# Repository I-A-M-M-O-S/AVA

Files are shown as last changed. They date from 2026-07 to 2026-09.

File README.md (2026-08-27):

# Ava
*Autonomous Vehicle for Alex*
## Goal
Autonomous 1:10 RC-Car utilizing a Jetson Orin System.

## Hardware

### Custom PCB
All the different ECUs and sensors need to be connected.
Point-to-point wiring is one option but very messy and prone to EMI, using a custom PCB instead.

PCB-Schematic
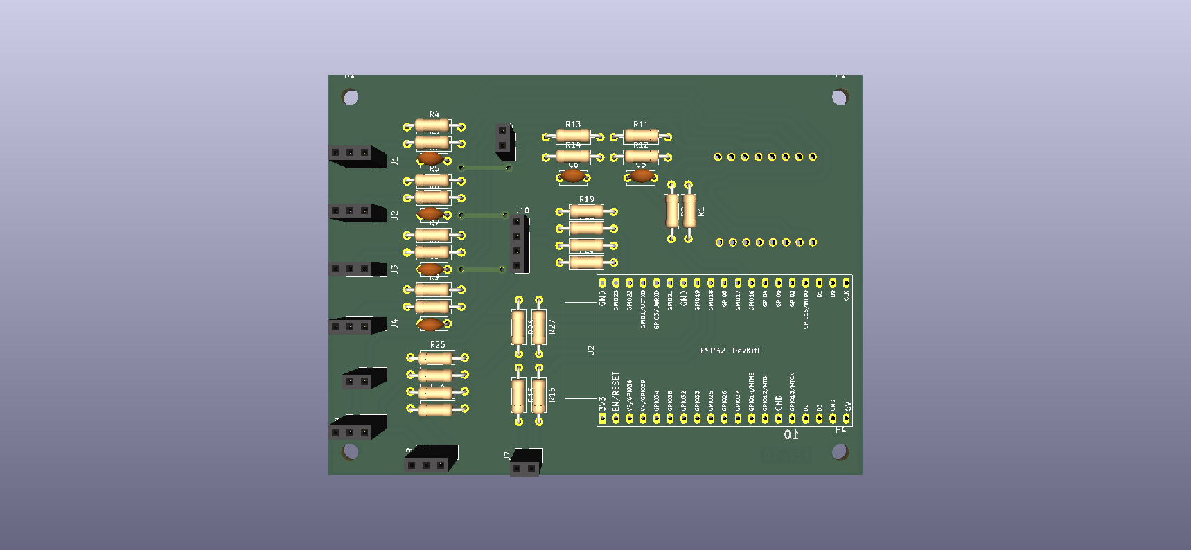
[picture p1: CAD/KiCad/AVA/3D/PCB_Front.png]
PCB-Front

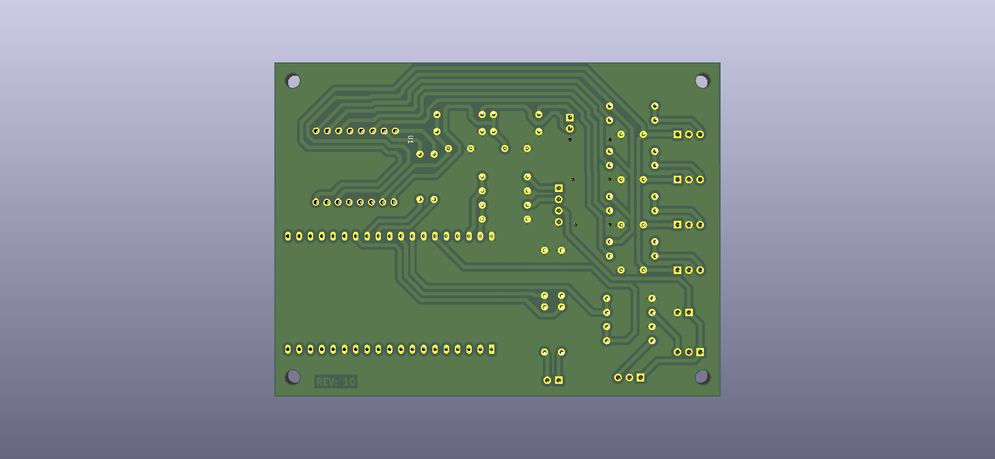
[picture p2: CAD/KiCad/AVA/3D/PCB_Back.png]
PCB-Back


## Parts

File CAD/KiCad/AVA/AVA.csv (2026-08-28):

Id | Designator | Footprint | Quantity | Designation | Supplier and ref
1 | A1 | Arduino_Nano | 1 | Arduino_Nano_ESP32
2 | C1, C2, C3, C4, C5, C6 | C_Disc_D5.0mm_W2.5mm_P5.00mm | 6 | 100nF
3 | J1, J2, J3, J4, J8, J9 | PinSocket_1x03_P2.54mm_Vertical | 6 | Conn_01x03_Pin
4 | J5, J6, J7 | PinSocket_1x02_P2.54mm_Vertical | 3 | Conn_01x02_Pin
5 | J10 | PinSocket_1x04_P2.54mm_Vertical | 1 | Conn_01x04_Pin
6 | R1, R2 | R_Axial_DIN0207_L6.3mm_D2.5mm_P10.16mm_Horizontal | 2 | 100R
7 | R3, R6, R8, R10, R15, R16, R18, R19, R23, R24 | R_Axial_DIN0207_L6.3mm_D2.5mm_P10.16mm_Horizontal | 10 | 330R
8 | R4, R5, R7, R9, R12, R14, R17, R20, R21, R22, R25, R26 | R_Axial_DIN0207_L6.3mm_D2.5mm_P10.16mm_Horizontal | 12 | 10K
9 | R11 | R_Axial_DIN0207_L6.3mm_D2.5mm_P10.16mm_Horizontal | 1 | 22K
10 | R13 | R_Axial_DIN0207_L6.3mm_D2.5mm_P10.16mm_Horizontal | 1 | 56K
11 | U1 | WEMOS_C3_mini | 1 | WEMOS_C3_mini

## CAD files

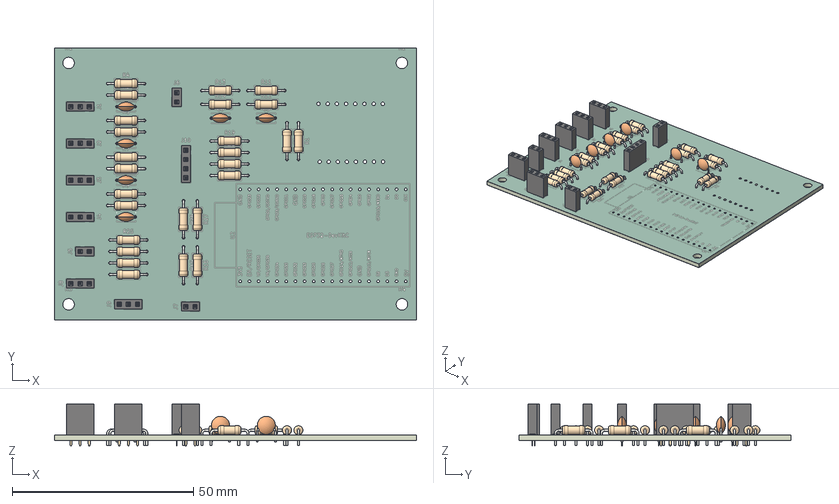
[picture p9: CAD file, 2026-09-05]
CAD/KiCad/AVA/FAB/STEP/AVA.step
100.0 x 75.0 x 11.6 mm
R_Axial_DIN0207_L63mm_D25mm_P1016mm_Horizontal x 26
PinSocket_1x02_P2.54mm_Vertical x 3
C_Disc_D50mm_W25mm_P500mm x 6
PinSocket_1x03_P2.54mm_Vertical x 6
PinSocket_1x04_P2.54mm_Vertical
AVA-unsaved-export-3enWX5_silkscreen x 2
AVA-unsaved-export-3enWX5_soldermask x 2
AVA-unsaved-export-3enWX5_PCB

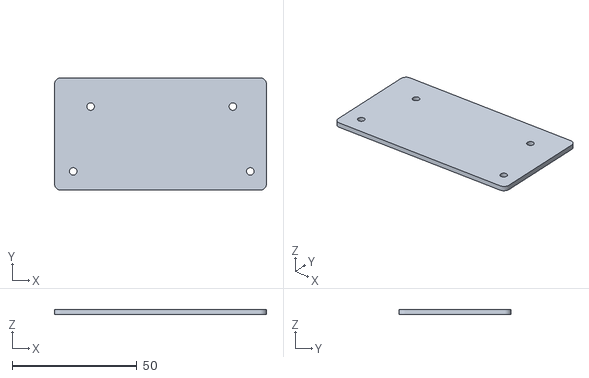
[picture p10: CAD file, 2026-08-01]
CAD/OpenScad/MGi_Lidar_Holder.stl
85.0 x 45.0 x 2.00

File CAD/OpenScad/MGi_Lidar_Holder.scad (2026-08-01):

drilling_d = 3;

linear_extrude(2){
	difference(){
		translate([-5,-5,0]){
			minkowski(){
				square([80,40]);
				circle(d=5, $fn=50);
			}
		}
		
		// D1
		translate([0,0,0]){
			circle(d=drilling_d, $fn=50);
		}
		
		// D2
		translate([71,0,0]){
			circle(d=drilling_d, $fn=50);
		}
		
		// D3
		translate([64,26,0]){
			circle(d=drilling_d, $fn=50);
		}
		
		// D4
		translate([7,26,0]){
			circle(d=drilling_d, $fn=50);
		}
	}
}

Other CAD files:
CAD/Fusion360/Carsen x10eb Mount1.f3d

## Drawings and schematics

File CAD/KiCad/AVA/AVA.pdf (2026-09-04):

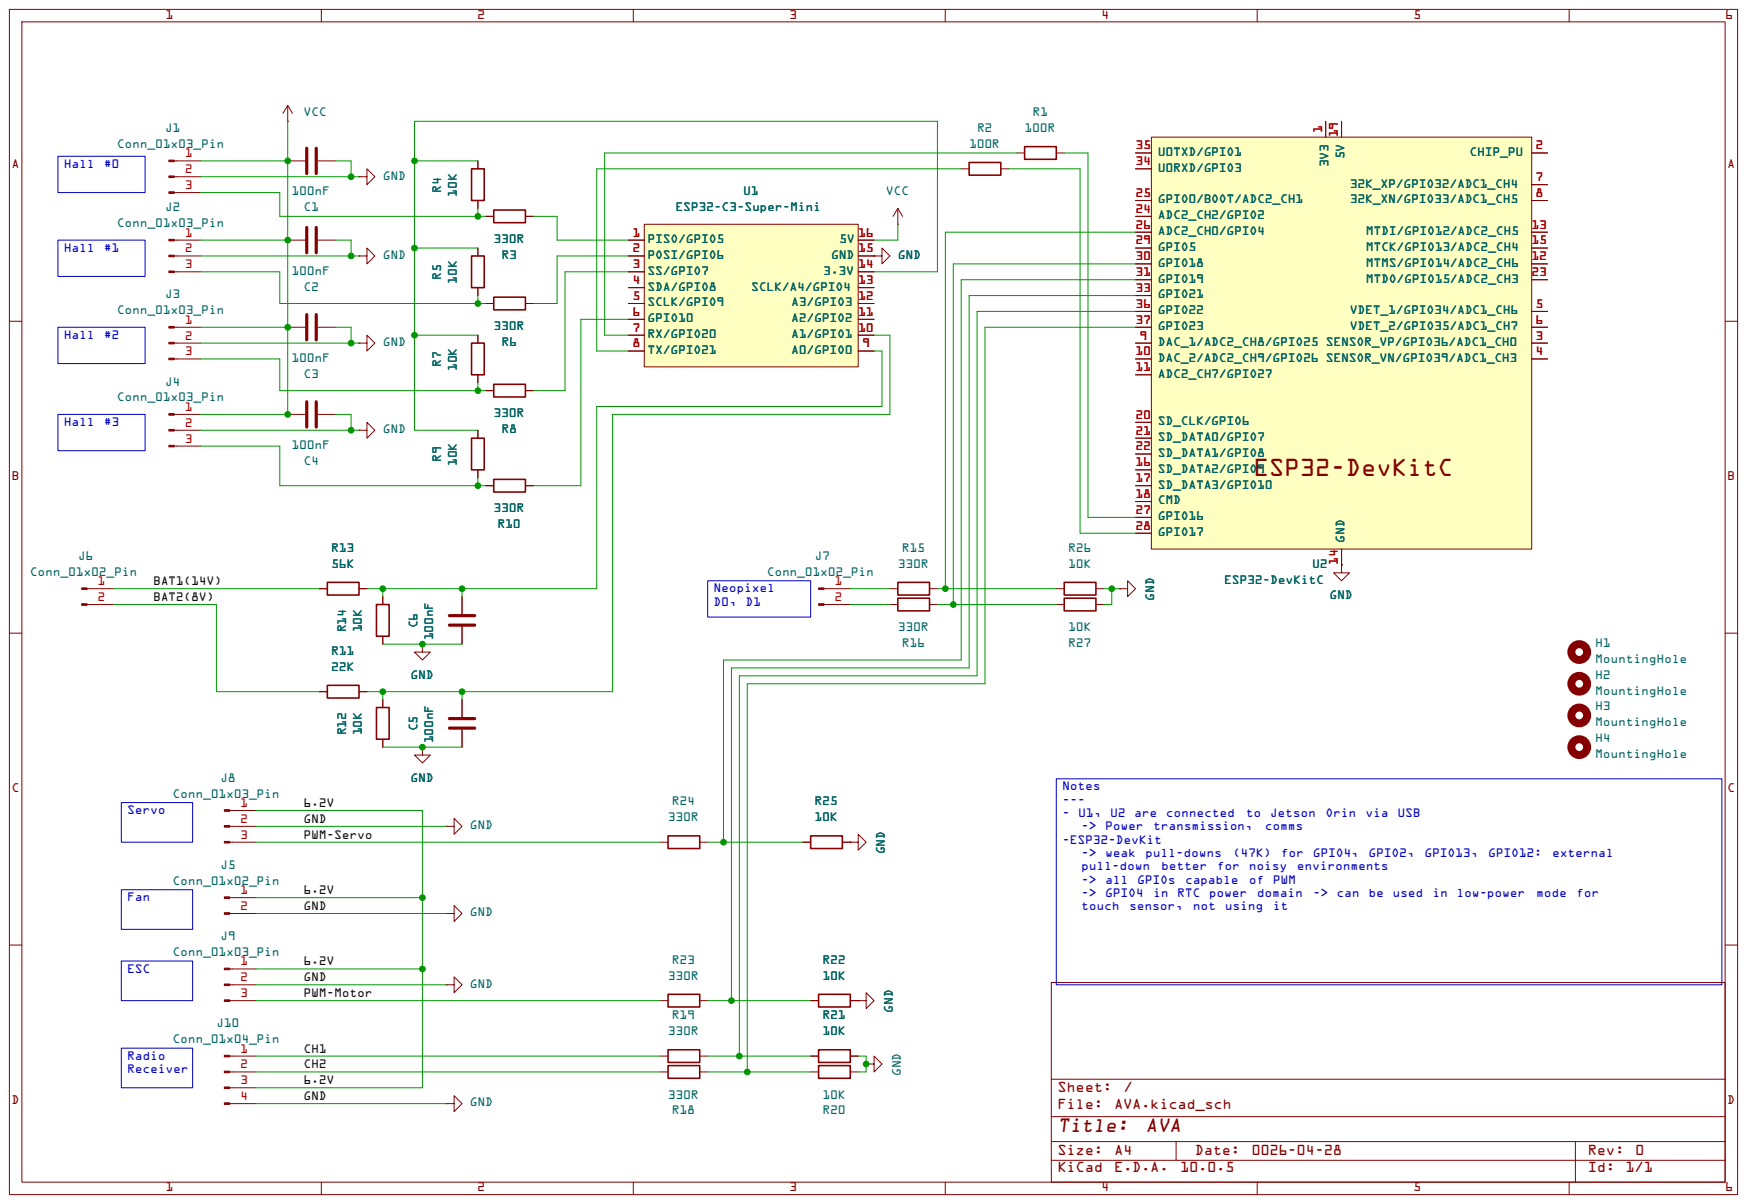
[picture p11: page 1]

Notes
- U1, U2 are connected to Jetson Orin via USB
-> Power transmission, comms
-ESP32-DevKit
-> weak pull-downs (47K) for GPIO4, GPIO2, GPIO13, GPIO12: external
pull-down better for noisy environments
-> all GPIOs capable of PWM
-> GPIO4 in RTC power domain -> can be used in low-power mode for
touch sensor, not using it

Size: A4 | Rev: 0
KiCad E.D.A. 10.0.5 | Id: 1/1

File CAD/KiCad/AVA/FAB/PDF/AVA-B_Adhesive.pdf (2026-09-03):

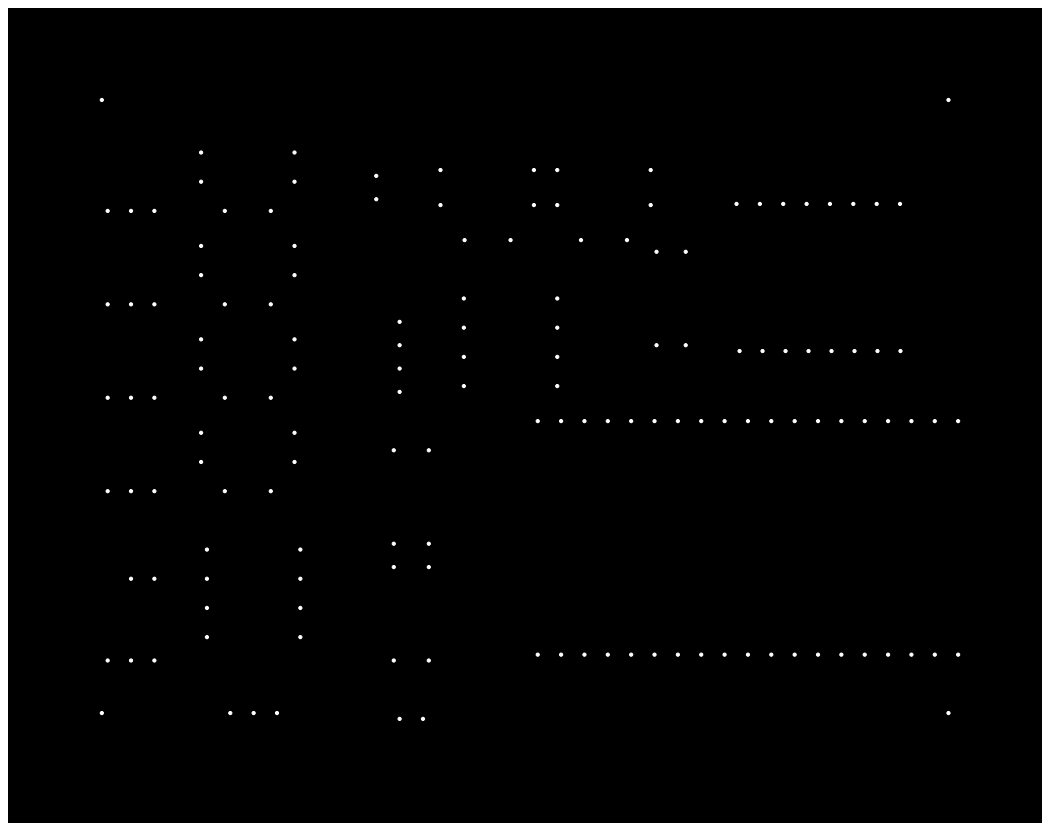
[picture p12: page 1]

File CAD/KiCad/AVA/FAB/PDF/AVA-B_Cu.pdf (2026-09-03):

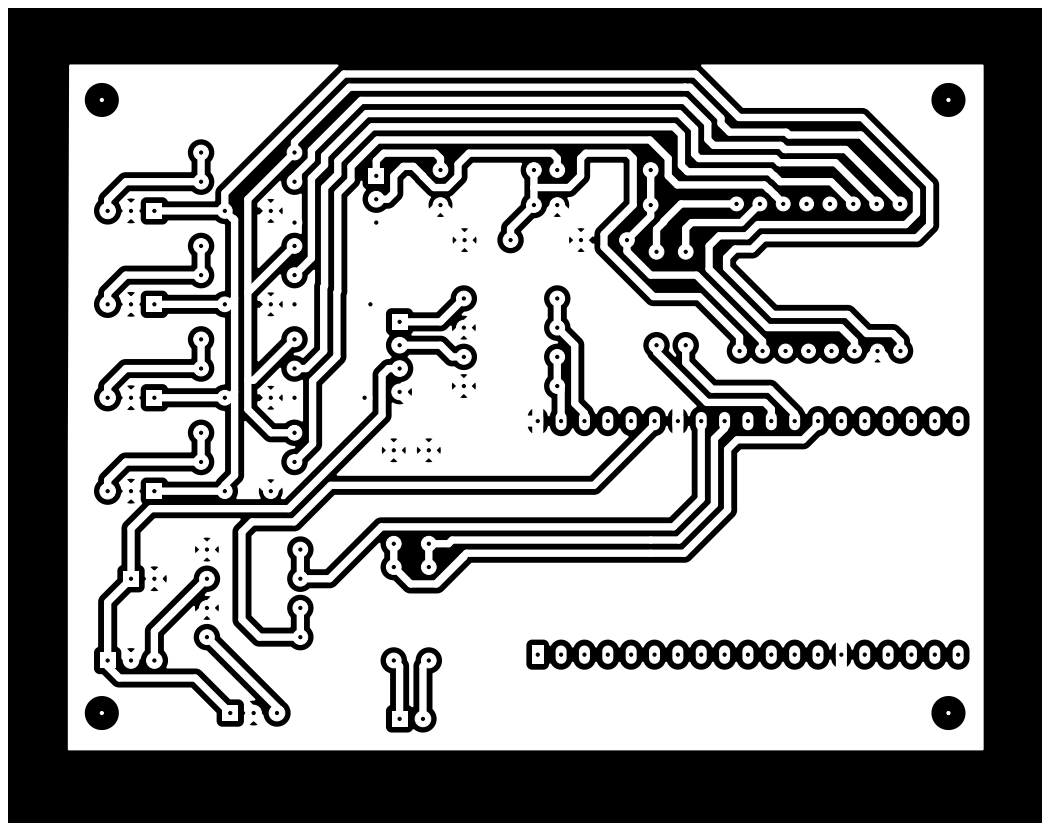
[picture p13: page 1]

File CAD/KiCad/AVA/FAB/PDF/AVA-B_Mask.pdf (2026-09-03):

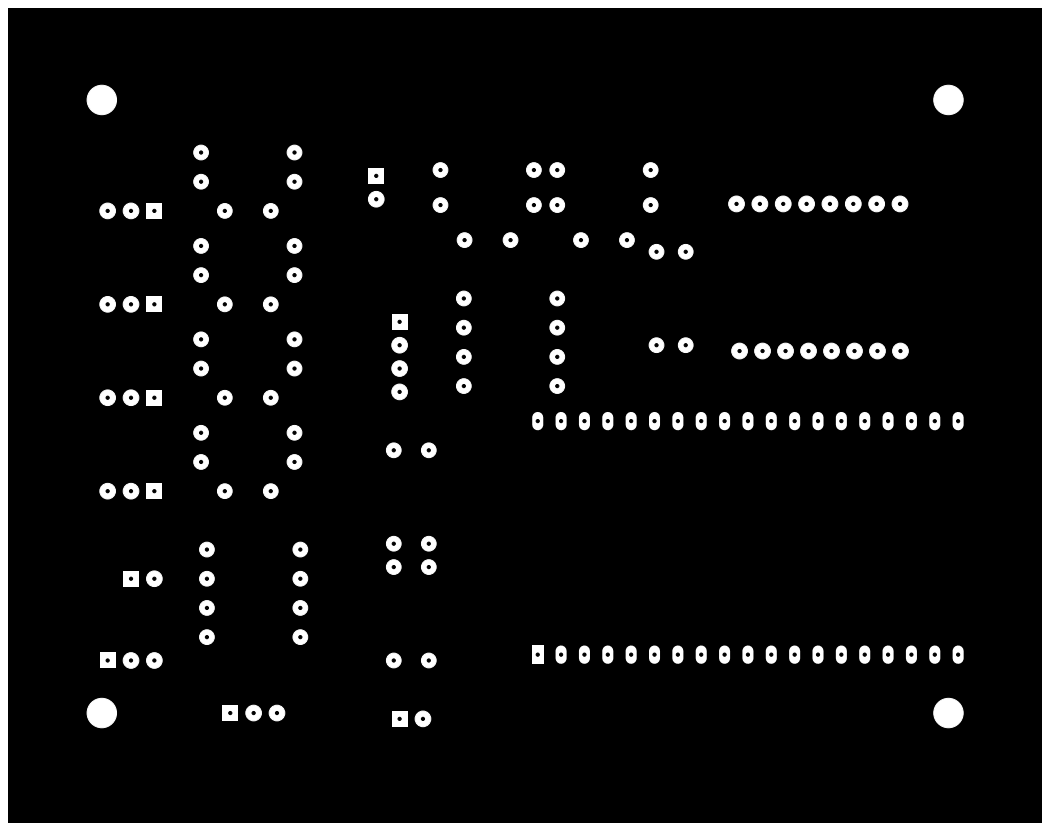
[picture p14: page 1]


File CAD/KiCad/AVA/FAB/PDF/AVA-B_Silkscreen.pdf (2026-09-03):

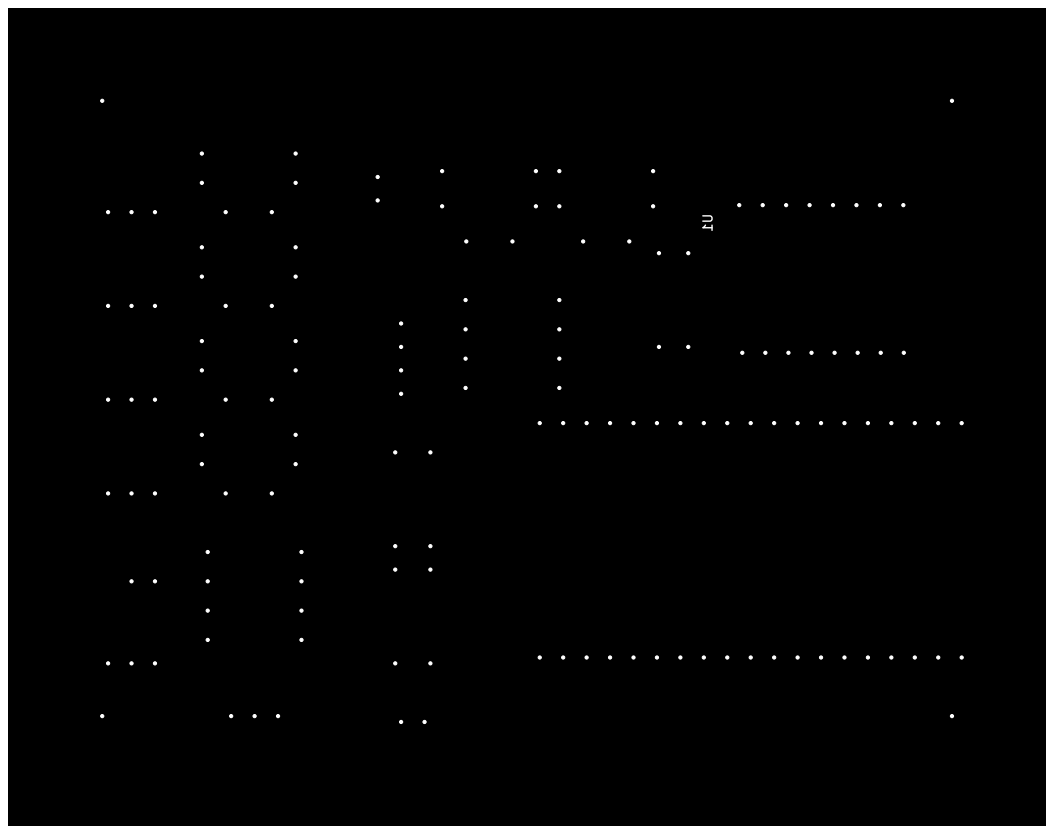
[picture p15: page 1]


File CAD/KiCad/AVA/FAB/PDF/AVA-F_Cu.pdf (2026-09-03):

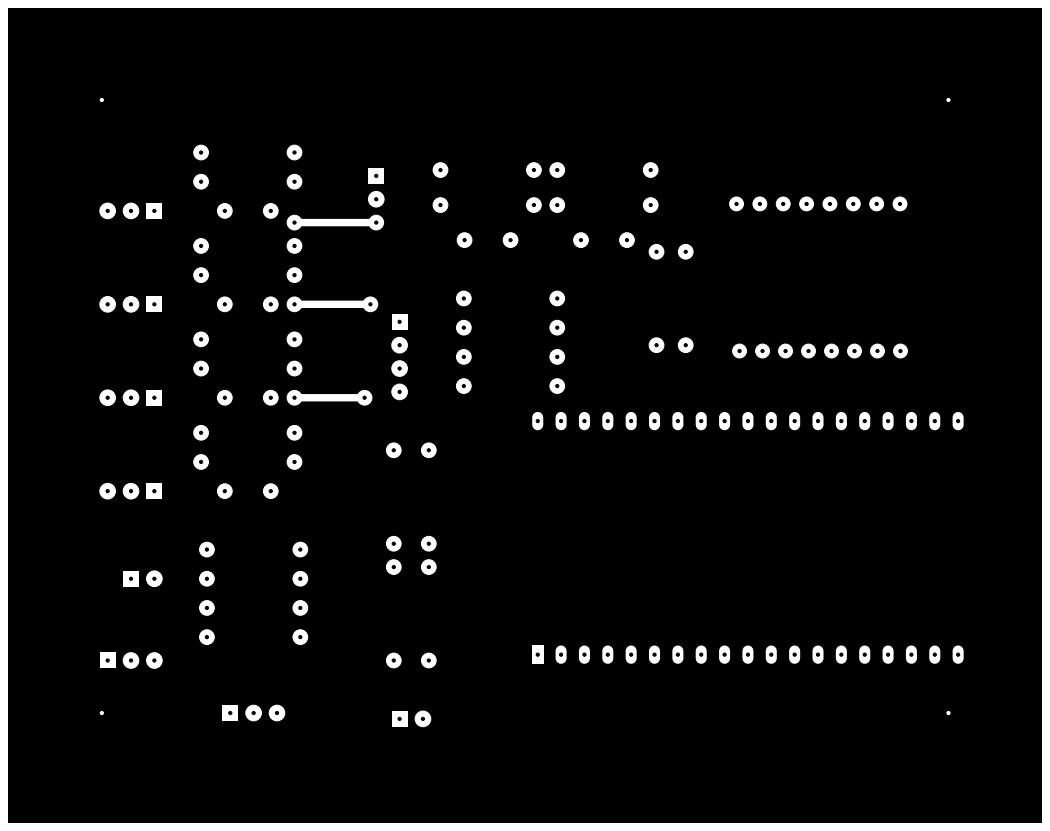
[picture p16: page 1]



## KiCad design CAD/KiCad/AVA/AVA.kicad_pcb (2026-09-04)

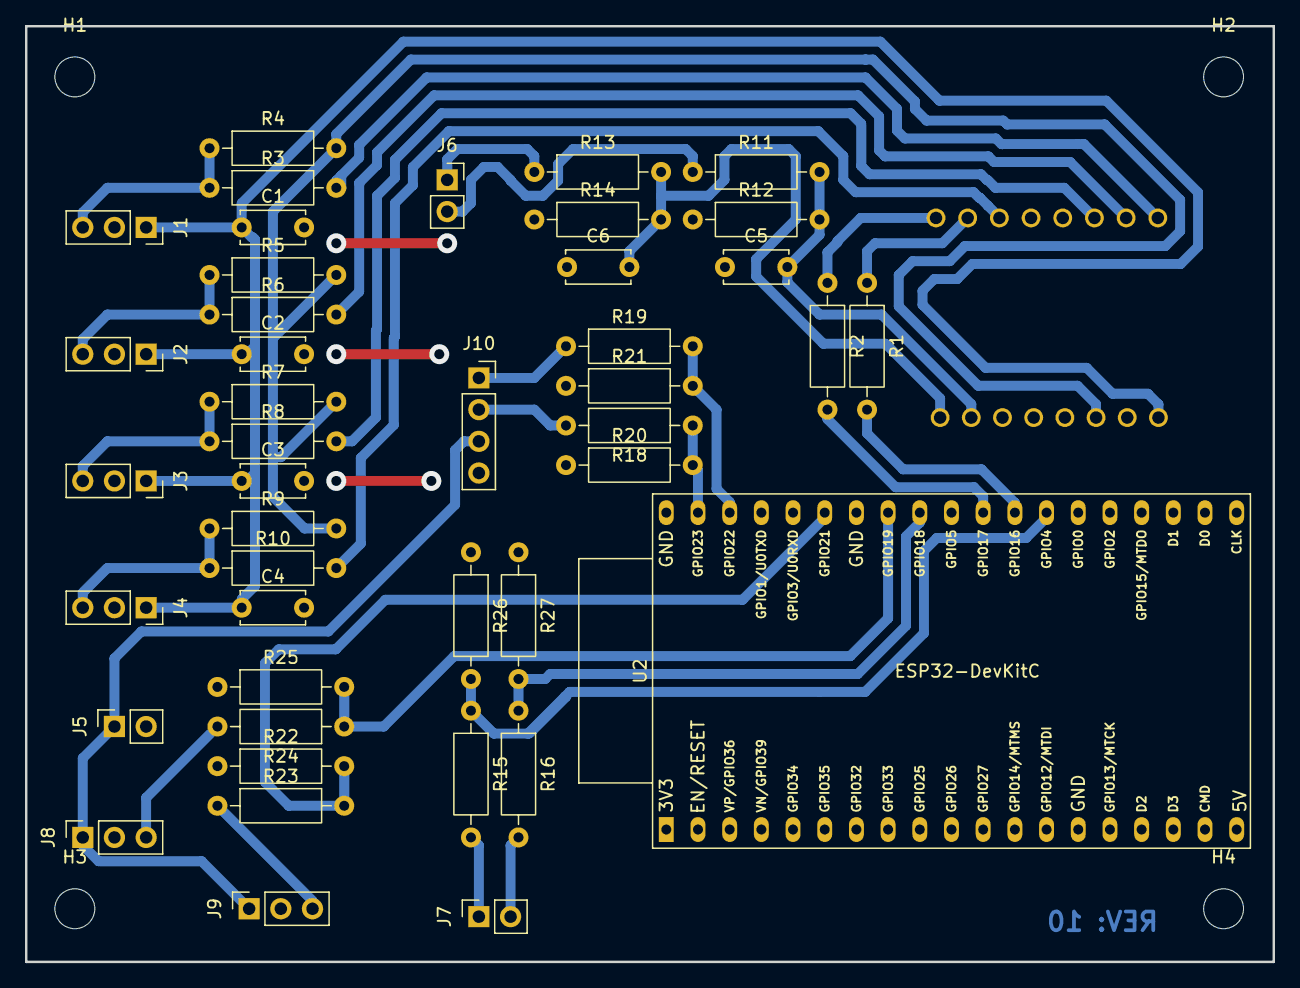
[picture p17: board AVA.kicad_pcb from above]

Board: 2 copper layers, 100.0 x 75.0 mm, 48 parts (1 on the bottom side), 32 nets.

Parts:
C1, C2, C3, C4, C5, C6: 100nF; C_Disc_D5.0mm_W2.5mm_P5.00mm
H1, H2, H3, H4: MountingHole; MountingHole_3.2mm_M3
J1, J2, J3, J4, J8, J9: Conn_01x03_Pin; PinSocket_1x03_P2.54mm_Vertical
J5, J6, J7: Conn_01x02_Pin; PinSocket_1x02_P2.54mm_Vertical
J10: Conn_01x04_Pin; PinSocket_1x04_P2.54mm_Vertical
R1, R2: 100R; R_Axial_DIN0207_L6.3mm_D2.5mm_P10.16mm_Horizontal
R3, R6, R8, R10, R15, R16, R18, R19, R23, R24: 330R; R_Axial_DIN0207_L6.3mm_D2.5mm_P10.16mm_Horizontal
R4, R5, R7, R9, R12, R14, R20, R21, R22, R25, R26, R27: 10K; R_Axial_DIN0207_L6.3mm_D2.5mm_P10.16mm_Horizontal
R11: 22K; R_Axial_DIN0207_L6.3mm_D2.5mm_P10.16mm_Horizontal
R13: 56K; R_Axial_DIN0207_L6.3mm_D2.5mm_P10.16mm_Horizontal
U1: ESP32-C3-Super-Mini
U2: ESP32-DevKitC

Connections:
/6.2V: J5.1, J8.1, J9.1, J10.3
/BAT1(14V): J6.1, R13.1
/BAT2(8V): J6.2, R11.1
/CH1: J10.1, R19.1
/CH2: J10.2, R18.2
/PWM-Motor: J9.3, R23.1
/PWM-Servo: J8.3, R24.2
GND: C1.2, C2.2, C3.2, C4.2, C5.1, C6.1, J1.2, J2.2, J3.2, J4.2, J5.2, J8.2, J9.2, J10.4, R12.1, R14.1, R20.1, R21.1, R22.1, R25.1, R26.1, R27.1, U1.15 (GND), U2.14 (GND), U2.32 (GND), U2.38 (GND)
unnamed: J1.3, R3.1, R4.1
unnamed: J2.3, R5.1, R6.1
unnamed: J3.3, R7.1, R8.1
unnamed: J4.3, R9.1, R10.1
unnamed: J7.1, R15.2
unnamed: J7.2, R16.2
unnamed: R4.2, R5.2, R7.2, R9.2, U1.14 (3.3V)
unnamed: C6.2, R13.2, R14.2, U1.9 (A0/GPIO0)
unnamed: C5.2, R11.2, R12.2, U1.10 (A1/GPIO1)
unnamed: R10.2, U1.6 (GPIO10)
unnamed: R3.2, U1.1 (PISO/GPIO5)
unnamed: R6.2, U1.2 (POSI/GPIO6)
unnamed: R1.1, U1.7 (RX/GPIO20)
unnamed: R8.2, U1.3 (SS/GPIO7)
unnamed: R2.1, U1.8 (TX/GPIO21)
unnamed: R15.1, R26.2, U2.26 (ADC2_CH0/GPIO4)
unnamed: R1.2, U2.27 (GPIO16)
unnamed: R2.2, U2.28 (GPIO17)
unnamed: R16.1, R27.2, U2.30 (GPIO18)
unnamed: R24.1, R25.2, U2.31 (GPIO19)
unnamed: R22.2, R23.2, U2.33 (GPIO21)
unnamed: R19.2, R21.2, U2.36 (GPIO22)
unnamed: R18.1, R20.2, U2.37 (GPIO23)
VCC: C1.1, C2.1, C3.1, C4.1, J1.1, J2.1, J3.1, J4.1, U1.16 (5V)

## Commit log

2026-05-15 Base foler structure and few external documents for the start
    [AVA.kicad_pcb, AVA.kicad_sch]
2026-06-22 Working on schematic.
    [AVA.kicad_pcb, BMU.kicad_sch]
2026-06-22 Absolutely barebones, borderline starving schematic done. Probably fucked up, earned ciggie break tho
    [AVA.kicad_sch, BMU.kicad_sch]
2026-07-31 Added Graphos MBSE json file necessary for model
    [AVA.kicad_sch, BMU.kicad_sch, Masterpiece.kicad_pcb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]
2026-07-31 HTML export of current SysML diagrams, still concept only
2026-07-31 Updated current models
2026-08-01 Added design models
    [MGi_Lidar_Holder.scad, MGi_Lidar_Holder.stl]
2026-08-01 Experienced severe psychosis during decomposition and added new sensor and undervoltage blocks. Garmin, generate 500 cigarettes
2026-08-16 Gaphor doesn't contain builtin primitives. Need to add tomorrow, added generic sensor signal chain for available sensors. Also need to add standard EE units and embedded terminology for proxy port fl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
2026-08-22 Dieffernzial Strebe für Carson X10EB
    [Carsen x10eb Mount1.f3d]
2026-08-23 ESP32-Nano for Wifi comms, ESP32-C3 for Hall Interrupt handling and BAT0, BAT1 voltage monitoring and wiring between ESC, servo and fan will be handlded on separate PCB for easier wiring. This schema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
    [AVA.kicad_sch]
2026-08-23 Base connections added to schematic. Plotted PDF for others
    [AVA.kicad_sch]
2026-08-23 Copy paste error, Hall sensors were labelled as Neopixels. Added 330R series, 10K pulldown resistor for servo-pwm, esc-pwm and neopixel D0, D1 data lines
    [AVA.kicad_sch]
2026-08-24 Had to reinitialize KiCad project. Previously selected Eurocard PCB template and couldn't change back. Got normal free template now. No errors, yet
    [AVA.kicad_pcb, AVA.kicad_sch, BMU.kicad_sch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]
2026-08-24 Added PCB constraints from other projects which used photomedia etching of layout. Works good enough, 0.35mm track width min and 0.65mm clearance most important. Or else high chance of copper bridges
    [AVA.kicad_pcb, AVA.kicad_sch]
2026-08-24 Accidentally used 1W instead of 1/4W resistor footprints. Corrected it
    [AVA.kicad_sch]
2026-08-24 Starting on tracks. PCB will be one-sided, billions must use wire bridges
    [AVA.kicad_pcb, AVA.kicad_sch]
2026-08-24 Need to figure out how to hotkey batch track deletion. Need more autism, administering 0.5cc of Covid-19 vaccine for enhanced performance
    [AVA.kicad_pcb]
2026-08-24 75% done. Signal integrity is a myth invented by Bosch to sell expensive cables
    [AVA.kicad_pcb]
2026-08-24 Done. 6 wiring bridges in total needed, rest looks good. Added front, back view of PCB to Readme.md to show business
    [AVA.kicad_pcb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]
2026-08-25 Added another hole for 3.3V, GND copper bridge
    [AVA-B_Cu.gbr, AVA-NPTH.drl, AVA-PTH.drl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]
2026-08-26 Startin PCB etching now. Printing edited layout with qpdfview adheres to dimensions.
    [AVA.kicad_pcb, AVA.kicad_sch]
2026-08-26 Tracks of U1-PIN1/PIN2 were too small at 0.4mm, increased where possible
    [AVA.kicad_pcb]
2026-08-27 Added schematic to README.md and updated svg files for laser fab
    [AVA.kicad_sch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]
2026-08-27 README doesn't include PDF apparently
    [AVA.kicad_sch]
2026-08-27 Changed to svg, might be visible now
    [AVA.kicad_pcb]
2026-08-28 Plotted SVG, GERBER, PS again. No new changes otherwise
    [AVA.csv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]
2026-08-28 New FAB folder for SVG, GERBER, ... output instead of single root saving
    [AVA-B_Adhesive.gbr, AVA-B_Cu.gbr, AVA-B_Mask.gbr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]
2026-08-28 Added folder for drill files
    [AVA.kicad_pcb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]
2026-08-28 Slight changes for layout necessary. We've a ESP32-C3-Super-Mini, not an ESP32-C3-Mini. Completely different pinout and footprint. Watch me add a custom footprint and blow my shit smooth off
    [AVA-B_Adhesive.gbr, AVA-B_Cu.gbr, AVA-B_Mask.gbr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]
2026-08-28 Using correct footprint now. Jarvis, more alcohol
    [AVA-B_Adhesive.gbr, AVA-B_Cu.gbr, AVA-B_Mask.gbr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]
2026-08-28 Back, front finished. Cropped svg for printing, 500 cigarettes
    [AVA.kicad_pcb]
2026-08-29 Track width min now 1.6mm. Double sided board, no pre-drawn holes in front, back svg for easy printing
    [AVA-B_Adhesive.gbr, AVA-B_Cu.gbr, AVA-B_Mask.gbr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]
2026-08-31 ESP32-C3-SuperMini and Arduino Nano ESP32 layout. Next variant ESP32-C3-SuperMini and ESP32-WROOM-32U
    [AVA.kicad_pcb, AVA.kicad_sch]
2026-08-31 Updated schematic for new ESP32-WROOM-DEVKIT
    [AVA.kicad_pcb, AVA.kicad_sch]
2026-09-01 Modern PCB-CAD software requires 7GB of RAM to open a window. Where did we go wrong. Layout finished
    [AVA.kicad_pcb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]
2026-09-01 AVA-B_CUEdit.svg final stand. ESP32-C3-SuperMini and ESP32-DevKitC
2026-09-01 Updated schematic plot, 3D export
    [AVA.kicad_pcb]
2026-09-01 Updated schematic SVG aswell
2026-09-01 Digital hall wire, using GPIO2/8/9 from ESP32-C3-SuperMini not necessary. Changed to digital only GPIO
    [AVA.kicad_sch]
2026-09-01 Rounded off U1-GPIO5 track. Nothing important, no need to redo etching if done
    [AVA.kicad_pcb]
2026-09-01 Moved U2-GPIO19 by 0.6mm. No changes
    [AVA.kicad_pcb]
2026-09-01 Moved connectors a bit further apart. Might use plugs now, don't know dimensions
2026-09-01 SVG update for connectors
    [AVA.kicad_pcb]
2026-09-01 ESP32-DevKitC UART pins shared with usb, changing it to GPIO16/17. GPIO5 is strapping pin, changing pwm channels to GPIO4,18,19,20,21,22,23. GPIO4 in RTC-power-domain (touch sensor for deep-sleep mod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
    [AVA.kicad_pcb, AVA.kicad_sch]
2026-09-01 Newest SVG, cropped. Footprints I'm flipping, my wrists I'm slitting
    [AVA.kicad_pcb]
2026-09-02 Removed copper islands from circuit
    [AVA.kicad_pcb]
2026-09-02 Added edges to Cu-Edit
    [AVA.kicad_pcb]
2026-09-03 SVG files need to be mirrored for laser etching. I'M A SCHIZODIPSHIT
    [AVA.kicad_pcb]
2026-09-04 Added revision on pcb layout and updated 3D view
    [AVA.kicad_pcb, AVA.kicad_sch]
2026-09-05 Added STL, STEP model of PCB
    [AVA.step]
2026-09-06 Added data flow IBD for v1
